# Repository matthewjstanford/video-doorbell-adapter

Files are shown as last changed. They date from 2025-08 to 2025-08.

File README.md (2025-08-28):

# Doorbell Circuit

This document describes the doorbell circuit project, why it is needed, and how I propose to solve the problem.

## Current Configuration

As of the start of this project the configuration is:

* Two Ubiquiti Doorbell buttons deployed, one at the front door, one at the side door
* The transformer is 3016MT 16V 30VA Doorbell Transformer
* Both doorbells are configured to use the doorbell adapter
* Chime is Broan mechanical chime
* Doorbell buttons are connected to the network via WiFi

### Theory of Operation

This is my understanding of how the system operates.

1. 16VAC is supplied by the transformer to the chimes
1. The doorbell button is connected to the chimes so that the current being supplied to the doorbell button passes through the chime coil.
1. Under normal conditions (doorbell button is not pushed) the doorbell button can draw a small amount of current (how much?) and not activate the chime.
1. When the button is pressed a relay is closed that shorts the wires in the doorbell button. This causes a large amount of current to flow through the circuit, which activates the chime coil.
1. The doorbell buttons contain a small battery that allows it to handle surges of power draw without activating the chime.

## Problem

There are two distinct issues that I believe can both be solved with a single circuit design.

1. Under periods of sustained high load (on very cold days in the winter, when the battery is presumably underperforming) the additional current draw will cause the chimes to hum. The hum is the striker vibrating within the coil.
1. I would like to replace the cheap Broan mechanical chimes with a much nicer 8 tone chime. These type of chimes are not compatible with the Ubiquiti style doorbell buttons.
    1. The chime is connected directly to the transformer.
    1. Activating the chime requires shorting a pin to one of the transformer leads. Since current isn't flowing continually through the doorbell buttons it can't work with a video doorbell. (See wiring diagram below)
    1. Since the trigger mechanism is quite different (current draw vs shorting a pin) there is no direct way to get the Ubiquiti buttons to work with the new chime.
    
**Simple Chime Wiring**

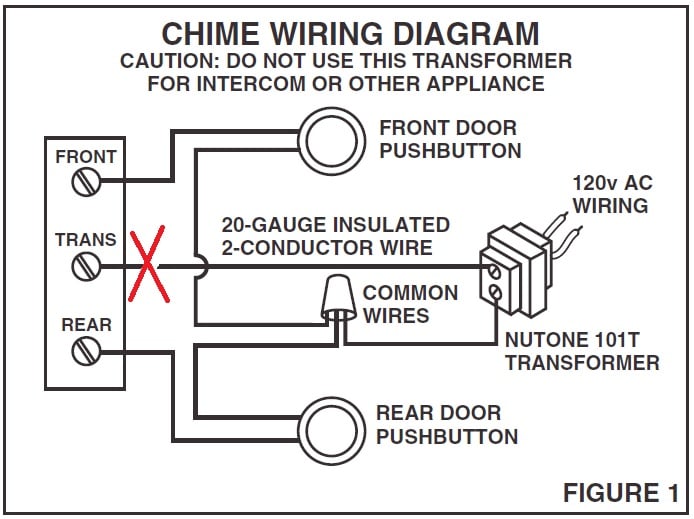
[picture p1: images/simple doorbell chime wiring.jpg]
Simple Chime Wiring


**New Chime Wiring**

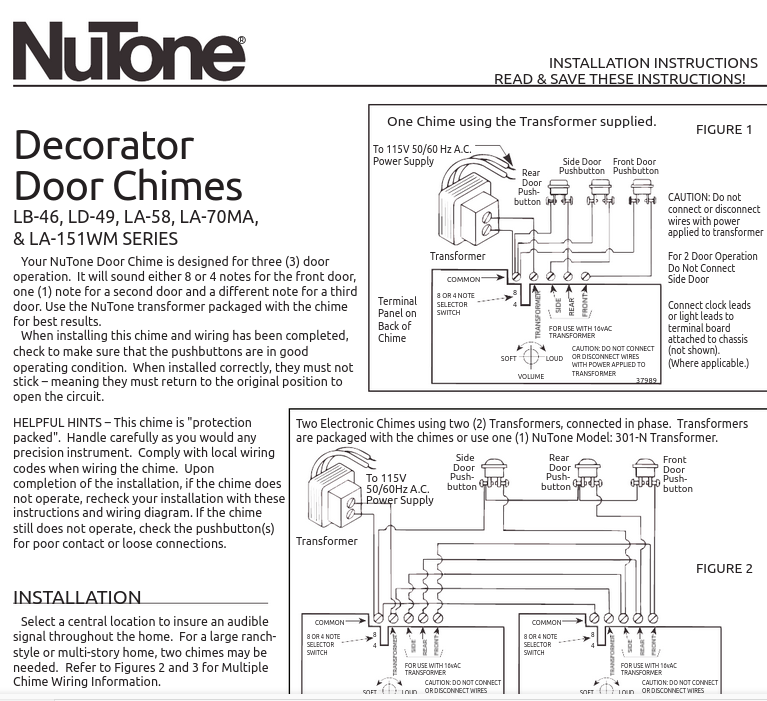
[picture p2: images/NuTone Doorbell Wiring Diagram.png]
NuTone Chime Wiring


**UniFi Protect Wiring**

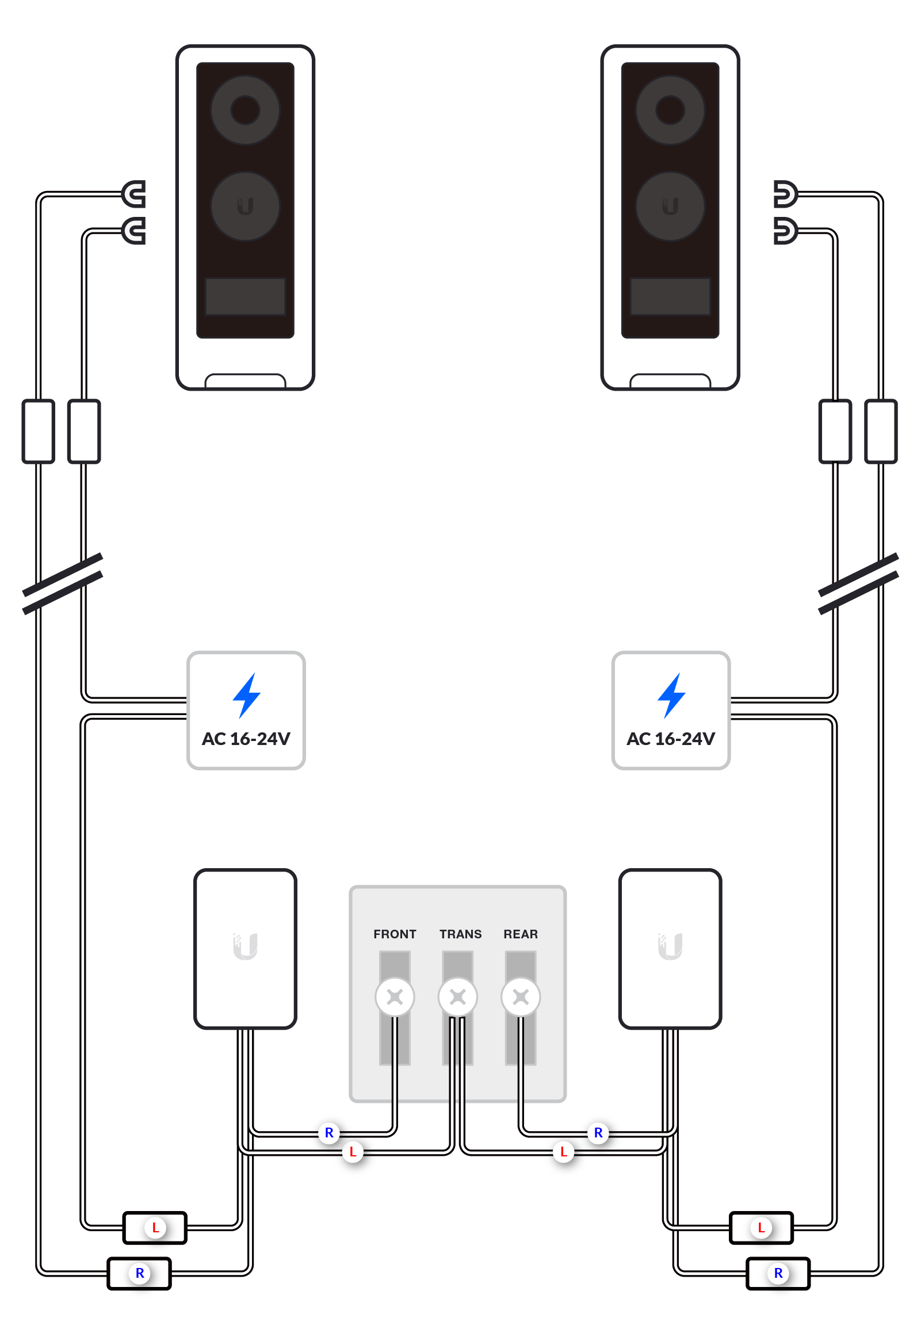
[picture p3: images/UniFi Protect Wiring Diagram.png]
UniFi Protect Wiring


## Idea

The general idea is to design a circuit that will sit in between the chime and the doorbell buttons. This circuit will constantly supply the buttons with current, and then will detect when current draw exceeds a threshold. Upon triggering the circuit will close a relay for a short period of time. The relay pins can be used to activate the Broan style current chime, or can be used to short the pin on the new style chime.

## Goals

Net power consumption on this circuit is a bit of a concern. Each additional doorbell button adds more load. The 30VA transformer should be quite sufficient for two doorbells and either chime configuration. We should keep the power consumption of the new circuit to a minimum.

I'd like to do this without using a microcontroller of any sort. We should be able to design this circuit with discrete components and build adjustability into things with potentiometers.

## Unknowns

The Ubiquiti doorbell buttons come with "doorbell adapters" that go in parallel with the doorbell button itself. What do those do? Are the capacitors?

How many doorbell buttons/chime configurations should the design support? It should support at least two, but should it support 3 or 4? In case more are added?

## Circuit Design

* A current transformer will be used to measure the current that is sent to the doorbell button.
* The CT output will be rectified into DC (peak detector) and fed into an OpAmp.
* The OpAmp will be configured as an inverting comparator with a potentiometer on the Vref to make the threshold tunable.
* The output of the OpAmp will be fed into a 555 timer in Monostable configuration.
* The 555 timer output can directly actuate a relay.
* Most of the circuit design is DC, so we will need to convert from 16VAC to 12VDC. Since power consumption is a primary goal we should use a buck/switching power supply. A switching regulator like the LM2575 should work.

## Discrete Components

And a brief description of why these specific components were selected.

* OpAmp - LM358
    * I had a bunch of these from a previous project.
* Switching Regulator - LM2575-12WT
    * A switching regulator was selected for power efficiency sake, and 12V was selected because it is near the input AC voltage and also because we will need to operate relays. Lower voltage relays are available, but we want to manage current by using higher voltage.
* Current Transformer - CT05-1000
    * This was selected for its small form factor and turn ratio. 1000:1. A 1A primary current will result in 1mA secondary.
* Burden Resistor - 6k (1A (est)/1000 = 1mA; 6V (half of 12V) / 1mA = 6k)
    * Assuming the doorbell will consume 1A when the button is pressed, we want around a 6V voltage spike as input to the OpAmp.

## Things I learned along the way

* The LM358 is a "single source" OpAmp, so it does not need a virtual ground
* A simple peak detector, like what we are considering here, should work great for this application.
* A 16 VAC source (our Doorbell transformer) will be close to 21 VDC once rectified. Using LM2575 to regulate it to 12 V should be totally fine.
* A linear voltage regulator is sometimes required after a switching regulator like the LM2575. This is because the switching regulator can introduce noise. In our case, however, this likely won't be an issue. No linear regulator should be required.

## Sub Assemblies

### Power Supply

The power supply needs to convert 16VAC to 12VDC and it needs to be as efficient as possible. The switching regulator, LM2575-12WT, is not adjustable. It will output 12V.

The AC input is rectified using 4 1N4002 diodes and a 470uF smoothing capacitor. The remainder of the circuit is based on the LM2575-12WT data sheet. A 330uF capacitor, 330uH inductor, and a 1N5817 Schottky diode are being used. The diode does not need to be a Schottky diode, but we are using the 1N5817 in other parts of the circuit, so we're just using it here now.

### Current Sensor

I am using a 1000:1 current transformer with a 6k burden resistor. This means that a 1A current on the primary should result in 1mA current on the secondary. 1mA across a 6k resistor should result in 6V. However, the 6V signal will only last a few milliseconds as this is a sine wave.

#### Peak Detector

The peak detector is meant to capture that peak voltage and store it for a period of time. This is to provide the downstream 555 timer a strong signal.

V(t)=V<sub>0</sub>e^−t/(RC)

* R=10 kΩ ( 1 x 10^4 )
* C=10 μF ( 1 x 10^-5 )
* Therefore RC = 1 x 10^-1 , or 0.1s or 100ms

In other words the voltage should decay 37% from the peak in around 100ms.

#### Amplifier

The operational amplifier is here to both invert the peak signal (take the voltage to zero) and to decouple the input signal from what we feed to the 555 timer.

### Timer

The timer portion of this circuit is necessary so that we can simulate a normal "press" of a doorbell button. This corresponds to the amount of time the relay stays closed.

The target should be around how long a doorbell button is normally held in the pressed position. But how long is that? Based on my own observation I suspect this is somewhere between 1/2 and 1 second.

As such I want the timer to stay activated somewhere in that range, but it should also be adjustable.

From the datasheet:

> For mono-stable operation, any of these timers can be connected as shown in Figure 9. If the output is low, application of a negative-going pulse to the trigger (TRIG) sets the flip-flop (Q goes low), drives the output high, and turns off Q1. Capacitor C then is charged through RA until the voltage across the capacitor reaches the threshold voltage of the threshold (THRES) input. If TRIG has returned to a high level, the output of the threshold comparator resets the flip-flop (Q goes high), drives the output low, and discharges C through Q1.

> Monostable operation is initiated when TRIG voltage falls below the trigger threshold. Once initiated, the sequence ends only if TRIG is high for at least 10 μs before the end of the timing interval. When the trigger is grounded, the comparator storage time can be as long as 10 μs, which limits the minimum monostable pulse width to 10 μs. Because of the threshold level and saturation voltage of Q1, the output pulse duration is approximately tw = 1.1RAC. Figure 11 is a plot of the time constant for various values of RA and C. The threshold levels and charge rates both are directly proportional to the supply voltage, VCC. The timing interval is, therefore, independent of the supply voltage, so long as the supply voltage is constant during the time interval.
Applying a negative-going trigger pulse simultaneously to RESET and TRIG during the timing interval discharges C and reinitiates the cycle, commencing on the positive edge of the reset pulse. The output is held low as long as the reset pulse is low. To prevent false triggering, when RESET is not used, it should be connected to VCC.

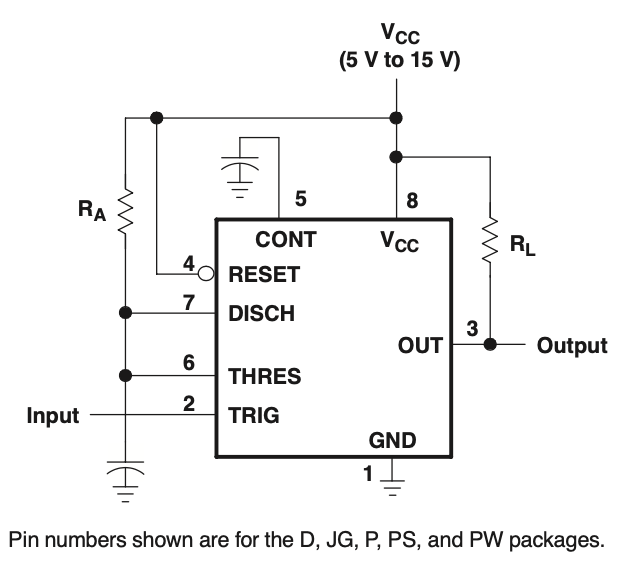
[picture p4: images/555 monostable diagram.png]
Monostable sample circuit 555 Monostable Schematic


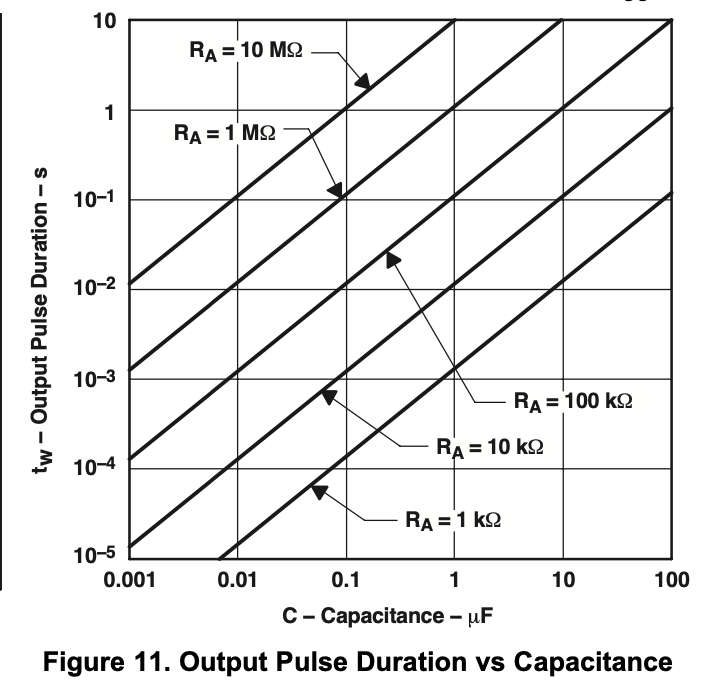
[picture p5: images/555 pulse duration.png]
Pulse duration


Using these charts we can see that with a 10uF capacitor and a 100k resistor (R<sub>A</sub> in diagram) we should be in the neighborhood of 1 second pulse duration. Varying the resistance with a 100k potentiometer will allow us to make adjustments to reduce the pulse duration.

## Breadboarding and testing

Several things got me along the way. Thankfully I was able to work through the issues.

This testing was done using a spare 120VAC -> 16VAC doorbell transformer that I purchased specifically for these tests.

1. Breadboard the 12V power supply
    1. Originally I had connected the diode backwards, which obviously won't work. Once that was corrected the power supply 
1. Breadboard the current sensor, and power it by the power supply
    1. I went through the current sensor first, then the peak detector, then the operational amplifier. I was able to confirm that a dead short on the 16VAC primary side of the CT resulted in around 5.6V across the burden resistor on the secondary. This is a little lower than I had anticipated, but it is fully in the range that should be workable.
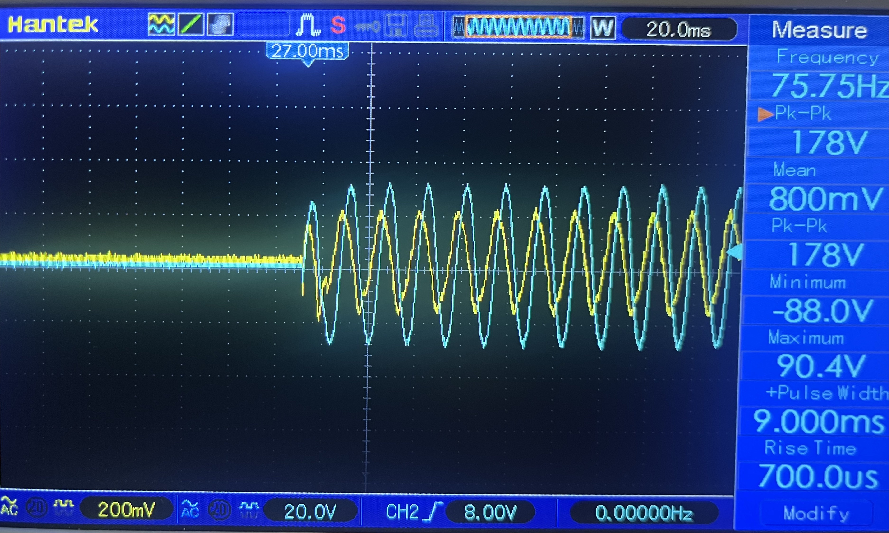
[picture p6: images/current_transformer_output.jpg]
Current Transformer

    1. I had made a mistake when creating the schematic of the peak detector. I had originally had the 10uF capacitor in-line between the diode and the OpAmp. Obviously this won't work. Once I realized my mistake I switched that capacitor to go between the output and ground, and things look good.
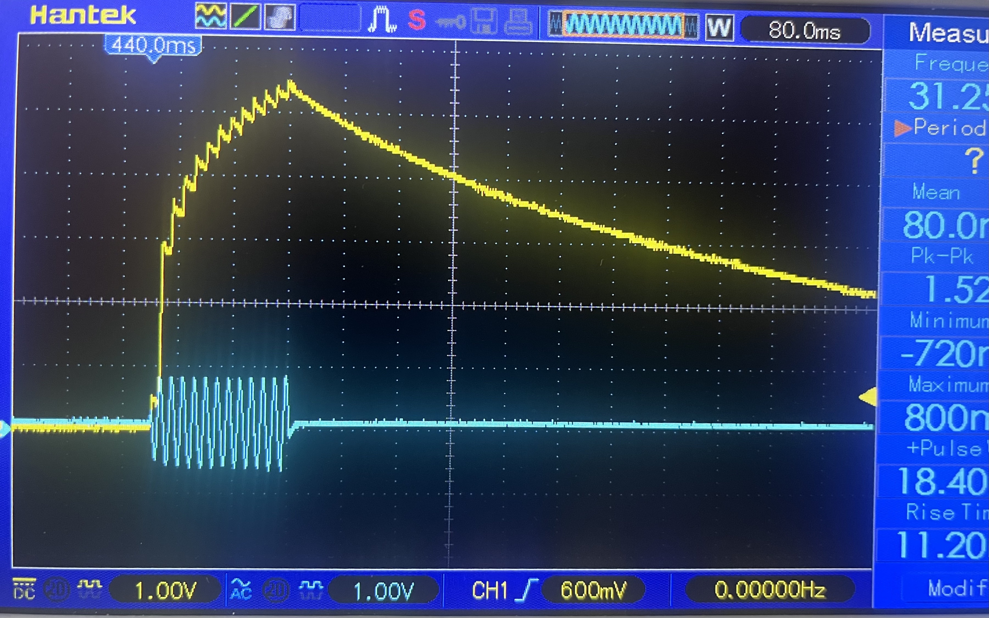
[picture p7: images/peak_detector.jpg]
Peak Detector

    1. I could not get the OpAmp to work correctly on the bench. I had the LM358 wired up according to the data sheet & schematic, but it didn't seem to be doing anything. Additionally I could see that the non-inverting input pin was sitting around 11V, where it should be 4V (voltage divider from potentiometer). Turns out I did have the chip wired correctly, but I had a broken wire, so the device wasn't grounded. Once that wire was replaced everything behaved as expected.
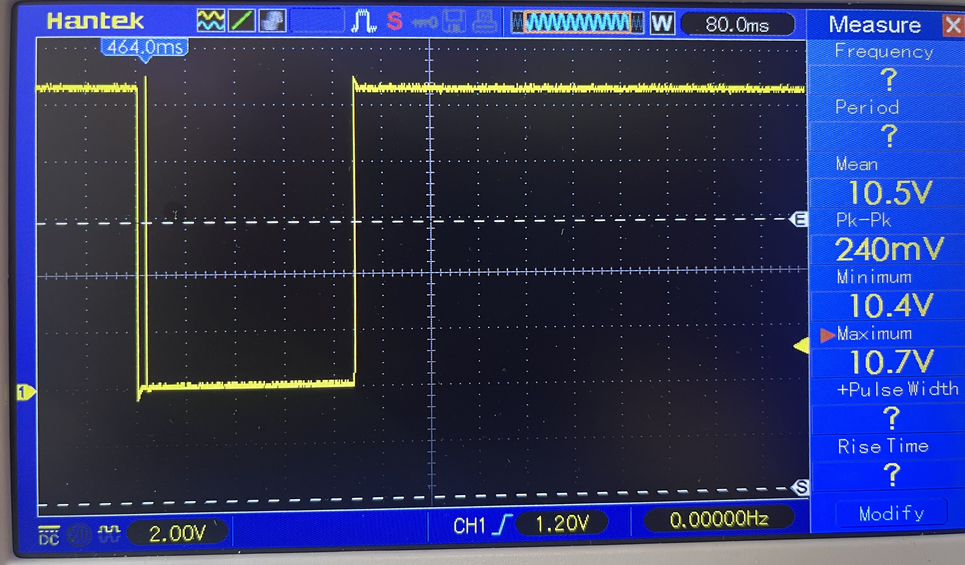
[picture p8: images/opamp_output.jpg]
OpAmp

1. Breadboard the timer & relay
    1. The timer circuit was verified on the bench and worked right out of the box. No issues were encountered here. I did confirm that the potentiometer would adjust the "press time". By default (middle of the range) the press time was around 0.7s.
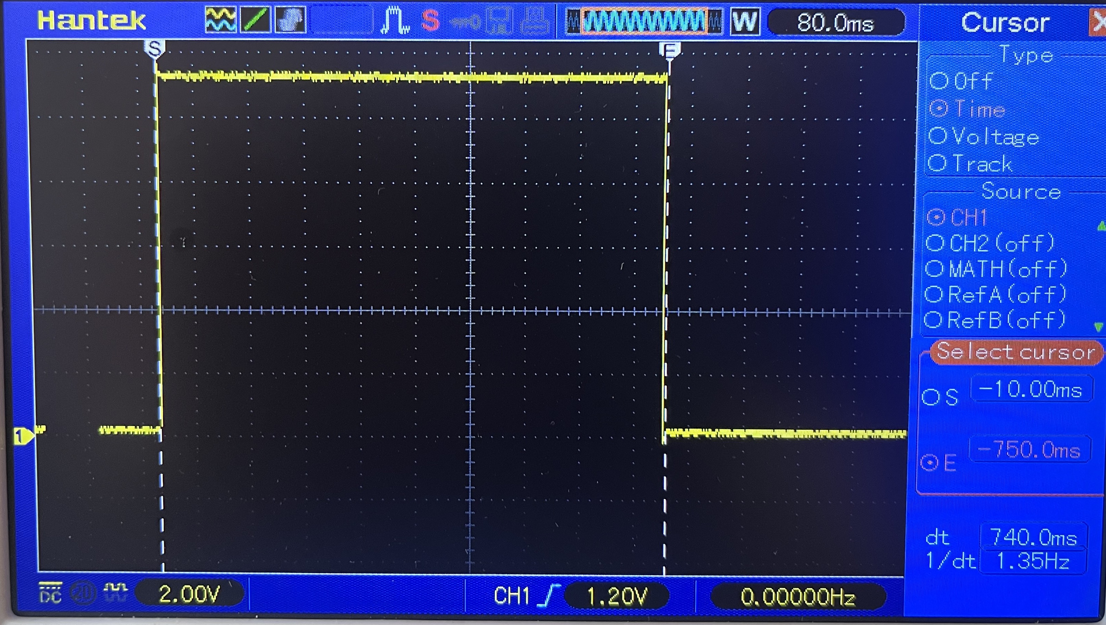
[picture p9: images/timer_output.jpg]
Timer Output

1. Switch simple doorbell button to a video doorbell
    1. I don't have a spare video doorbell, so this step was skipped for now.
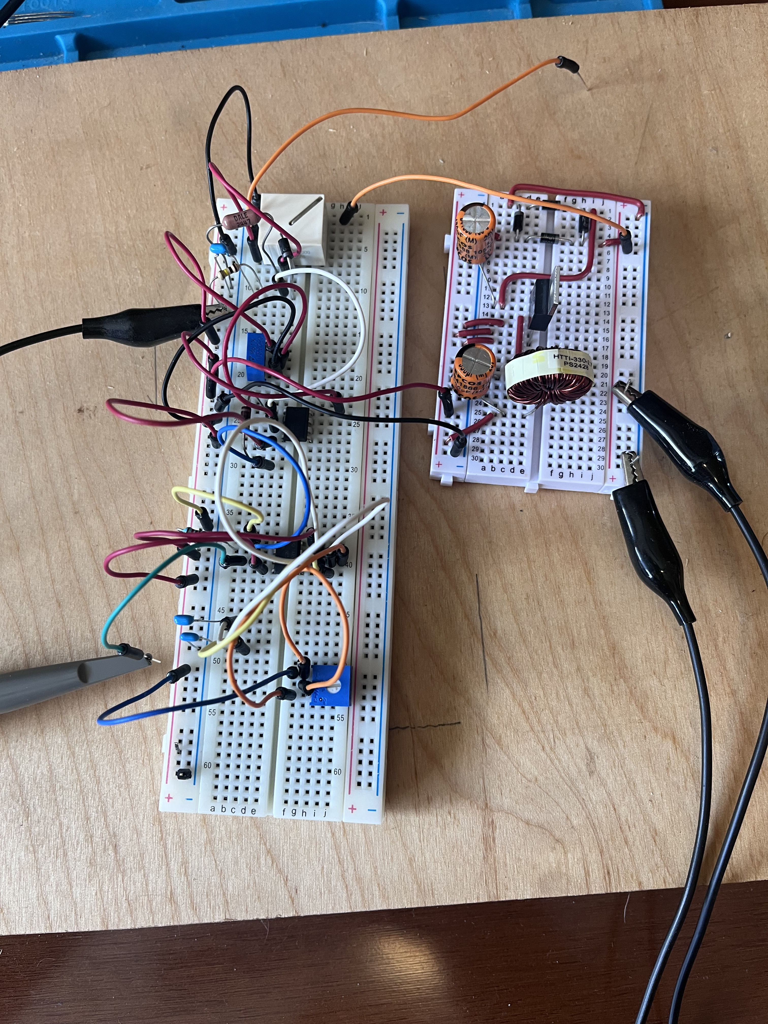
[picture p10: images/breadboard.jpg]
breadboard breadboard construction

1. Design PCB in KiCad
    1. This was my first ever PCB layout & creation. I had good design intentions when starting the layout, but it quickly devolved into chaos. I've come to realize that intuition is a key component to good design. That probably applies to all disciplines.
    1. I believe what I ended up with is a functional PCB, but it isn't pretty. Because this is my first ever layout, I'm running with it. I fairly certain if I were to start with a clean sheet and do it all again I would end up with a much better product. If it turns out there are any issues with the PCB then I'll just start over.
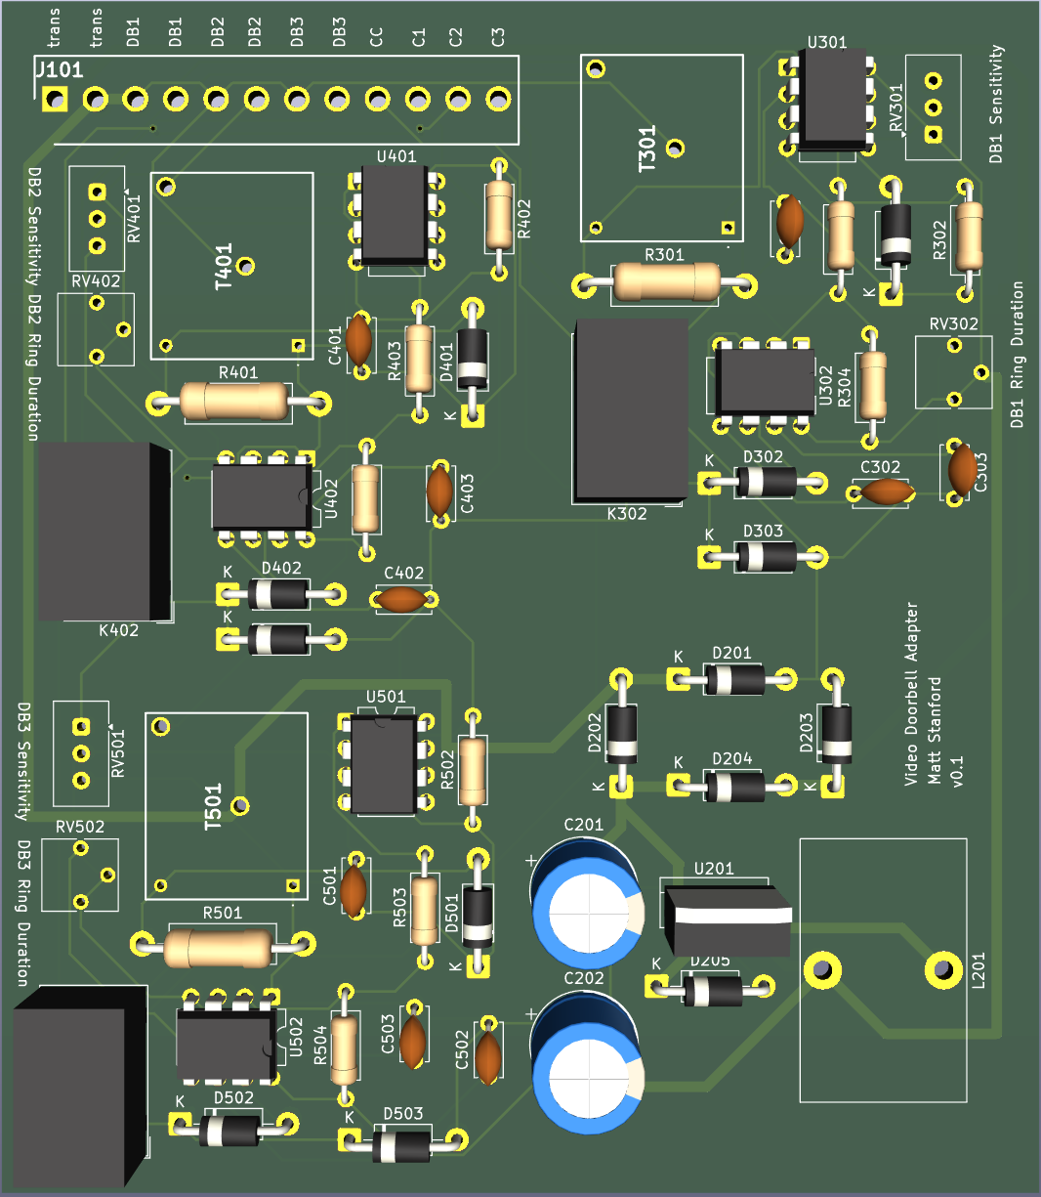
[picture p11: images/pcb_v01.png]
pcb PCB Image


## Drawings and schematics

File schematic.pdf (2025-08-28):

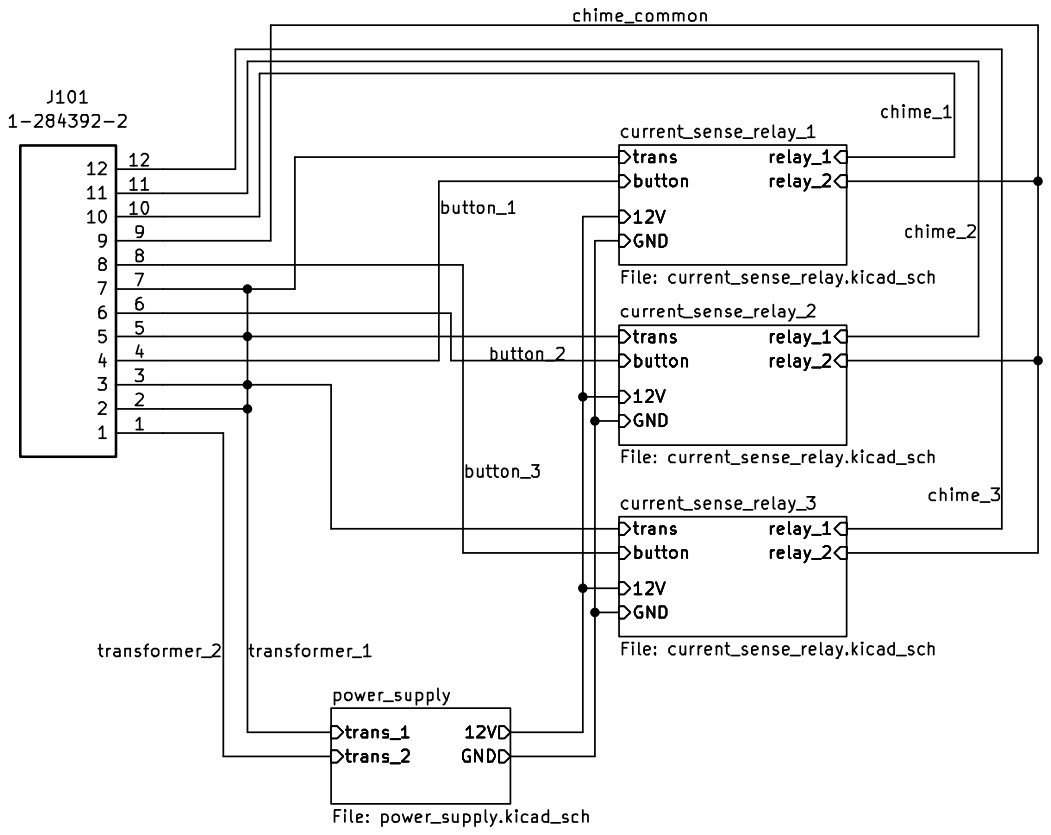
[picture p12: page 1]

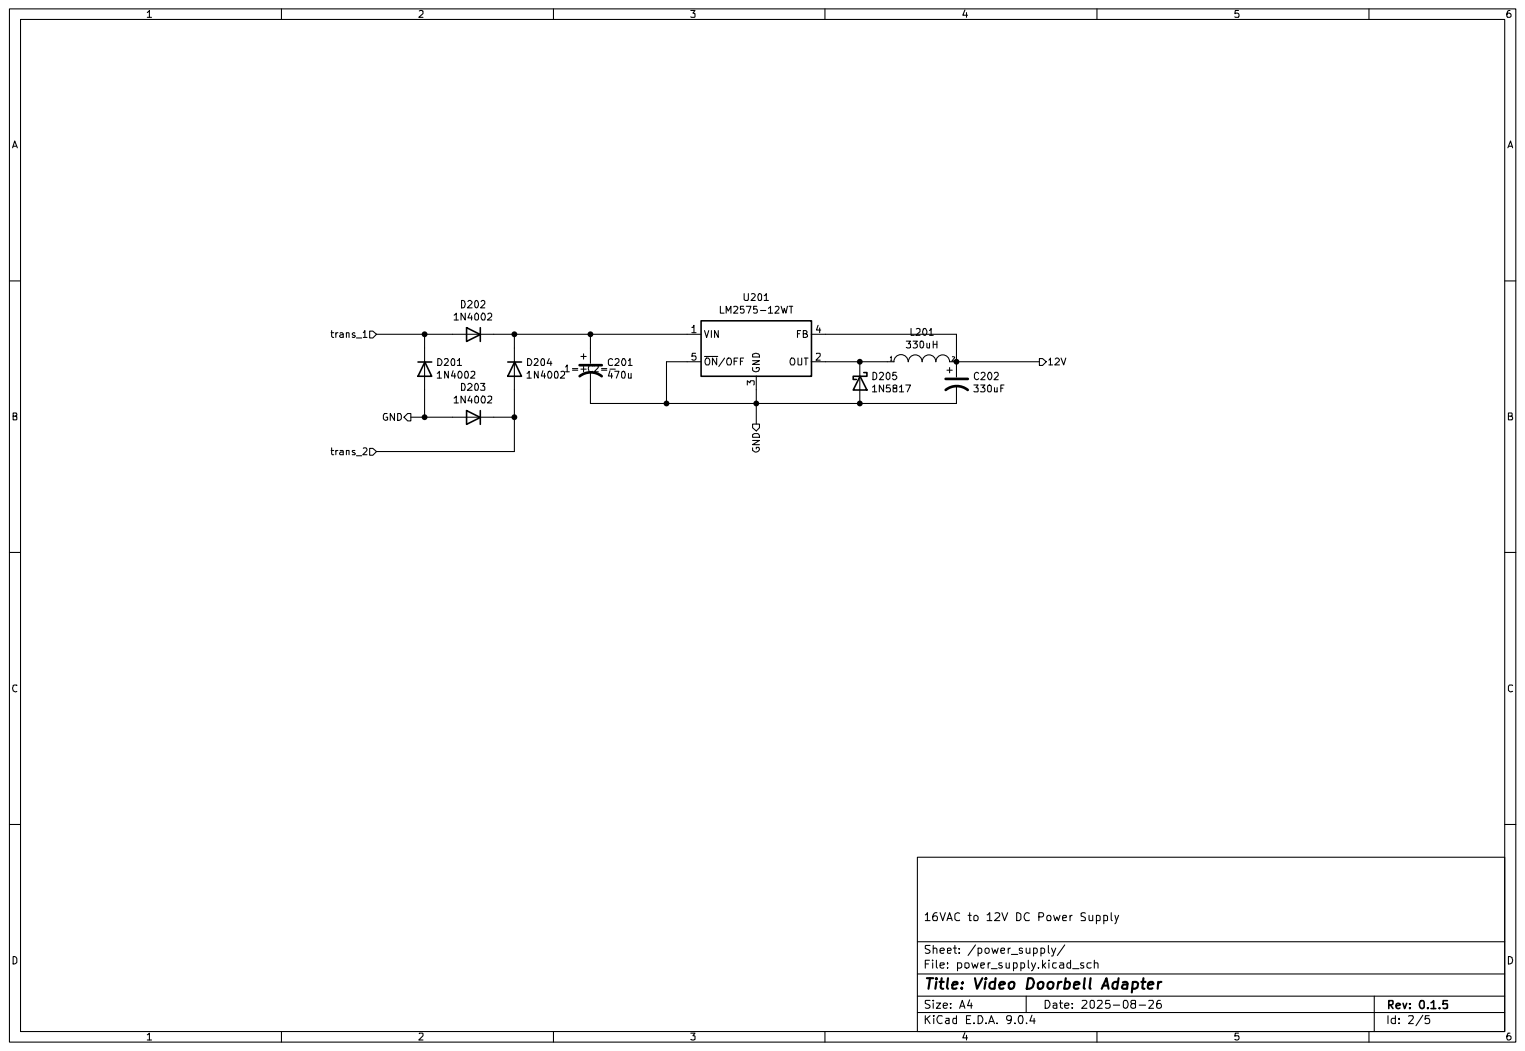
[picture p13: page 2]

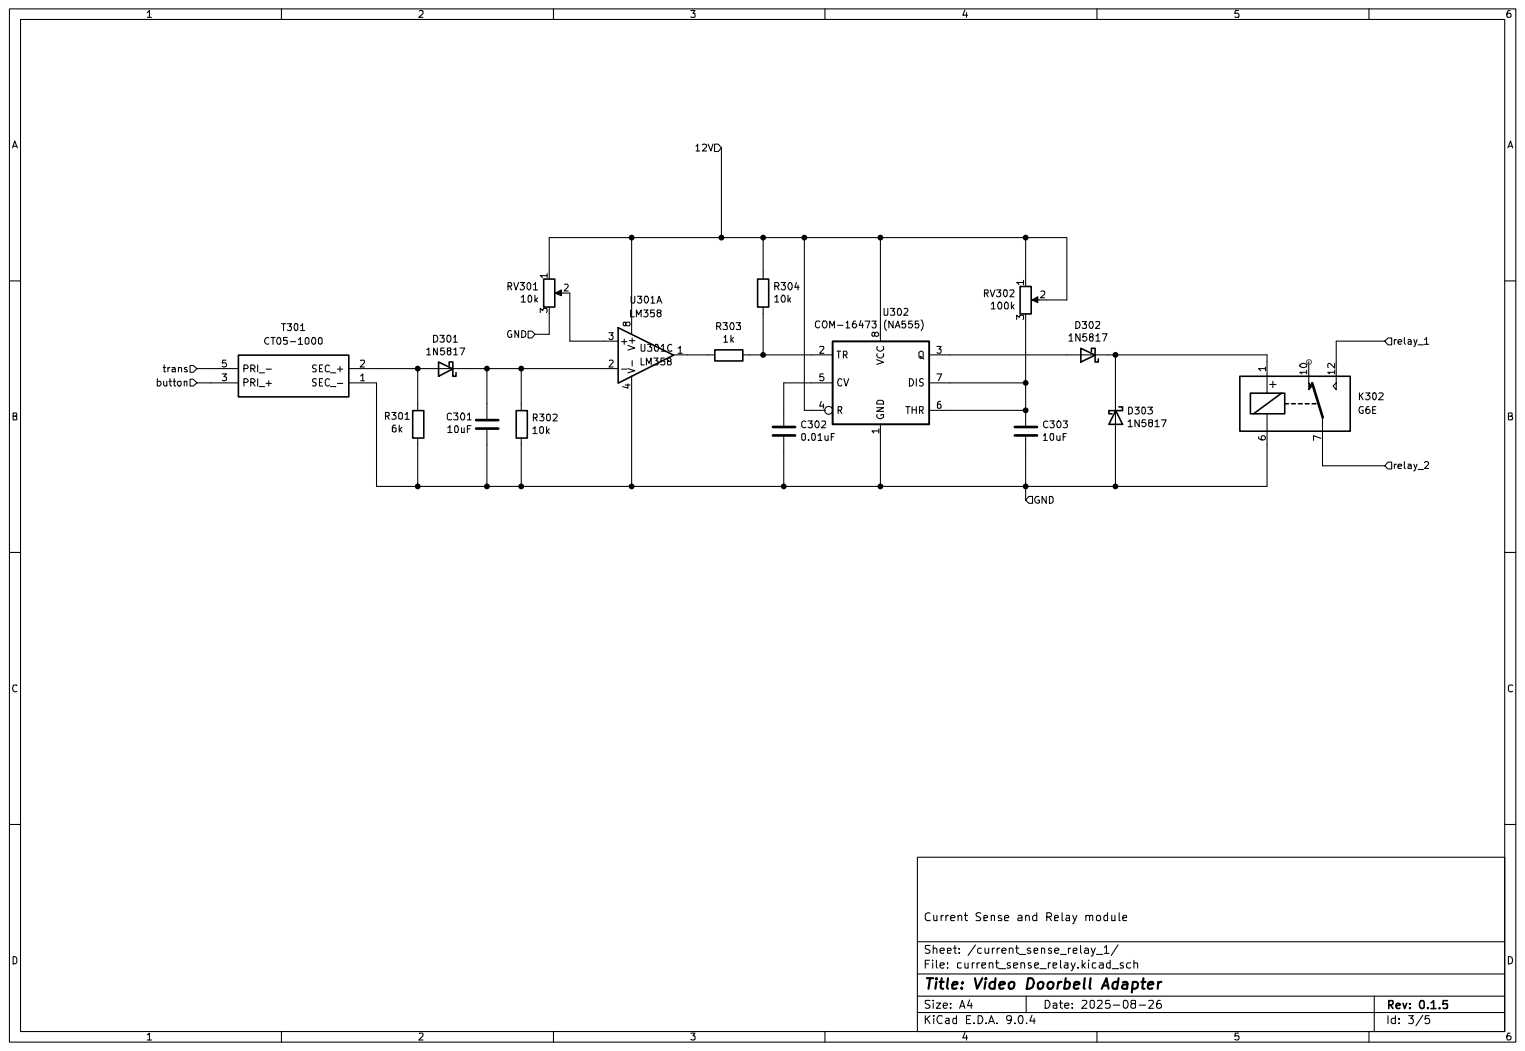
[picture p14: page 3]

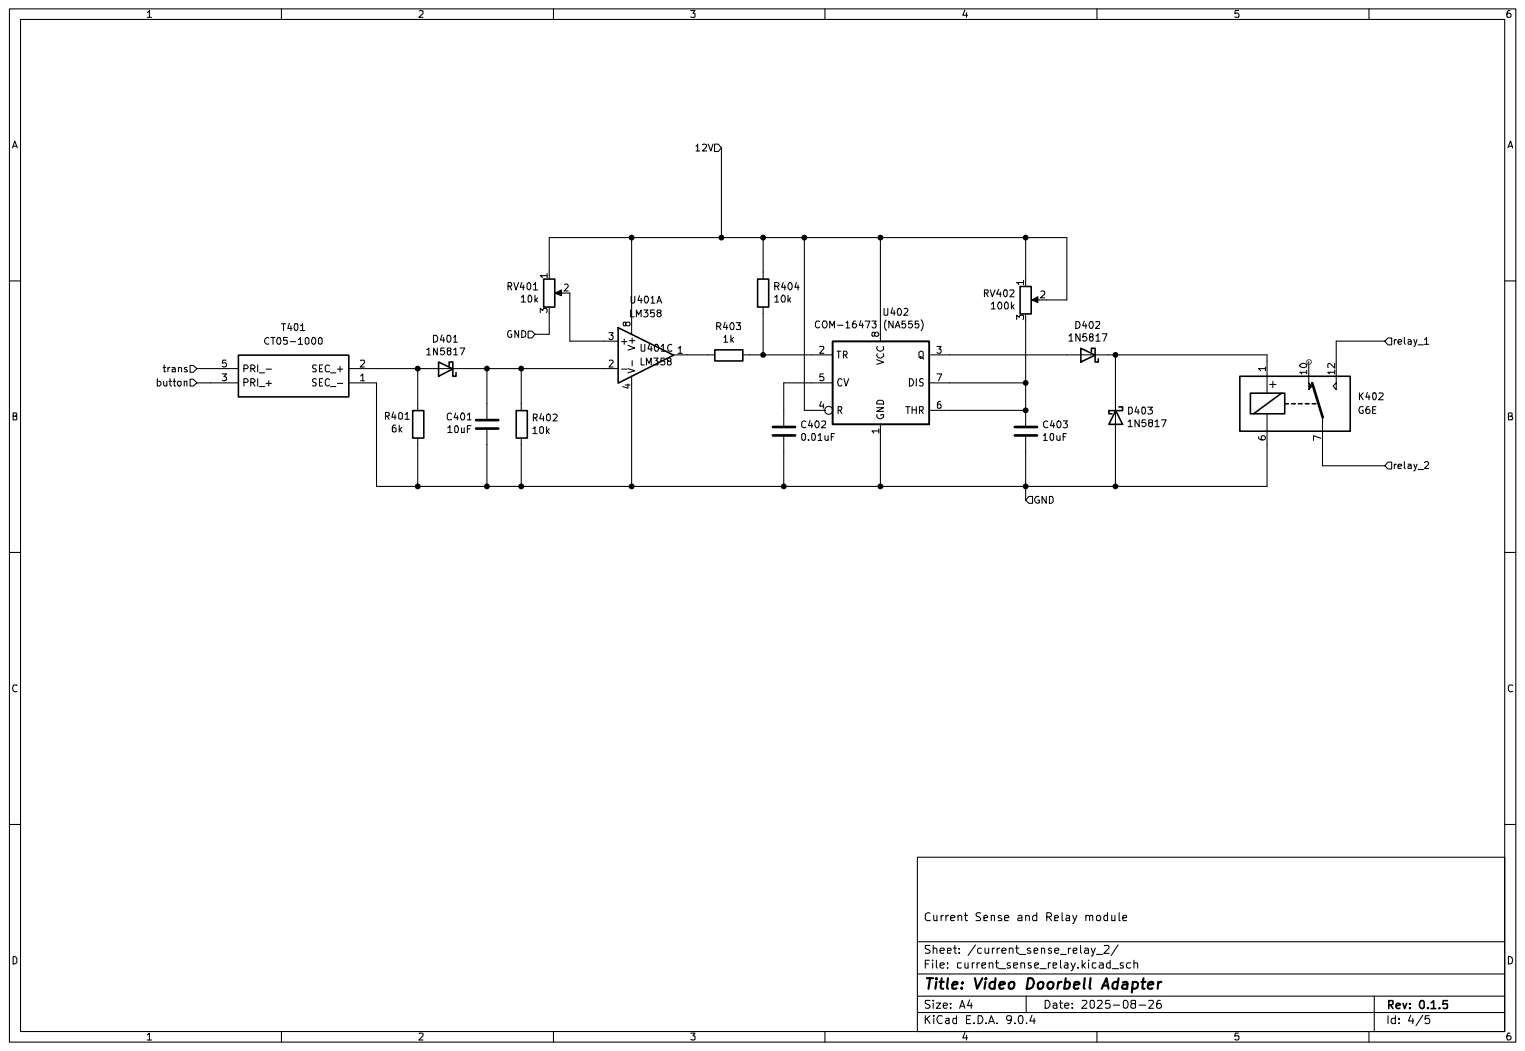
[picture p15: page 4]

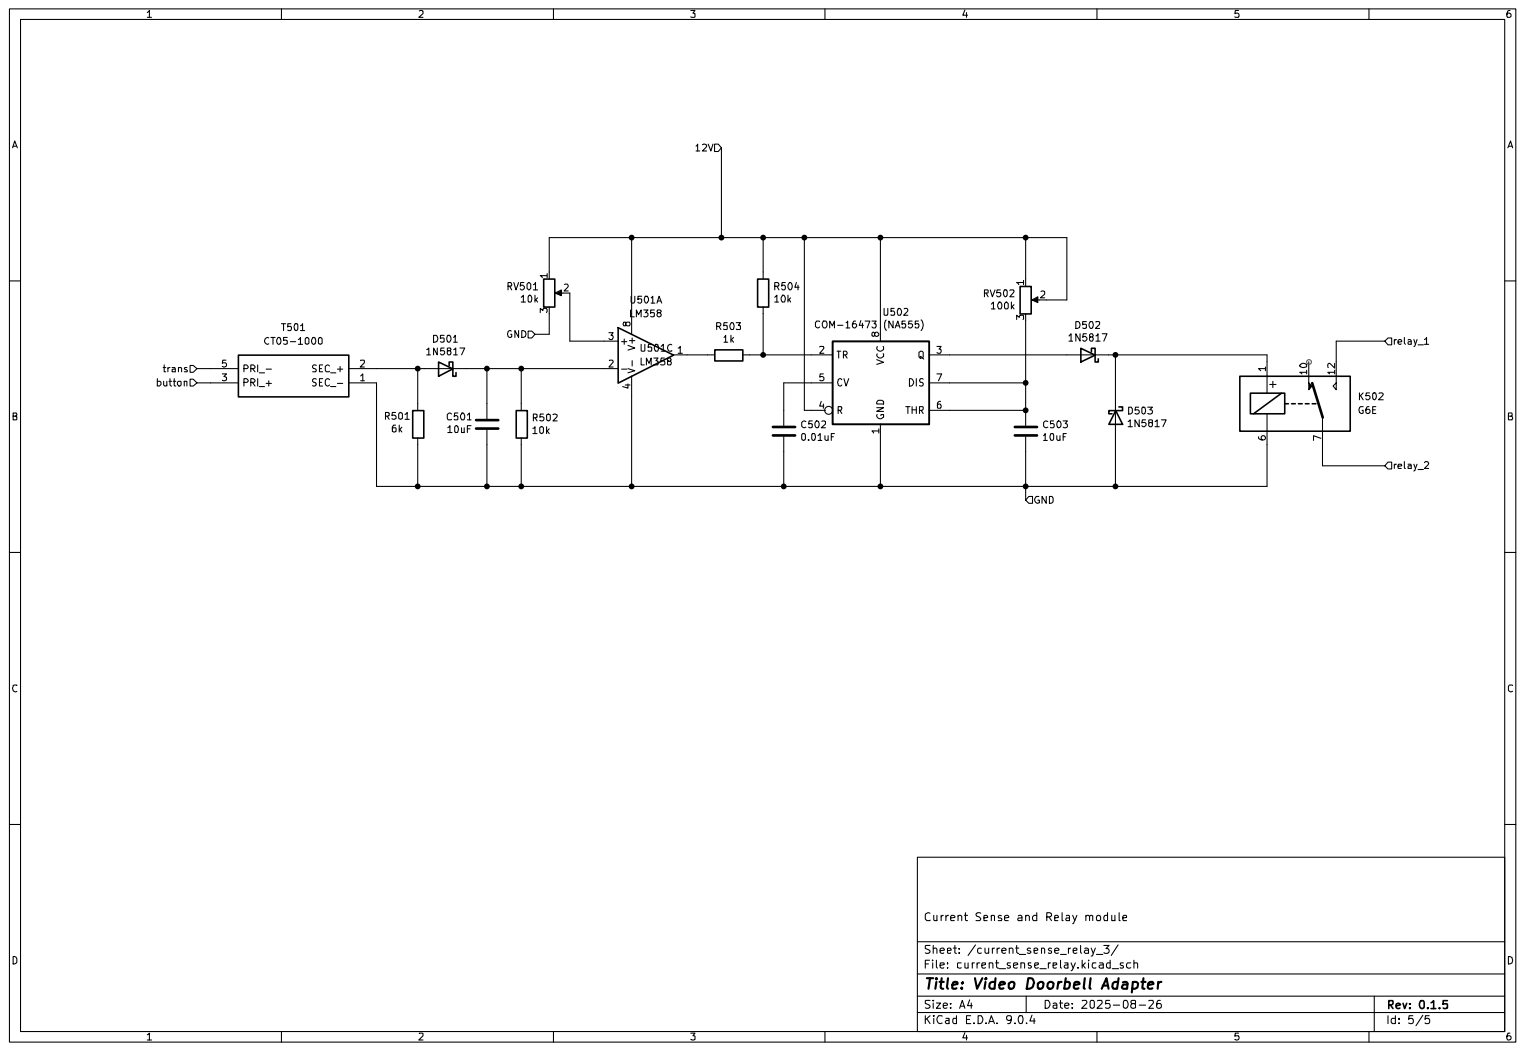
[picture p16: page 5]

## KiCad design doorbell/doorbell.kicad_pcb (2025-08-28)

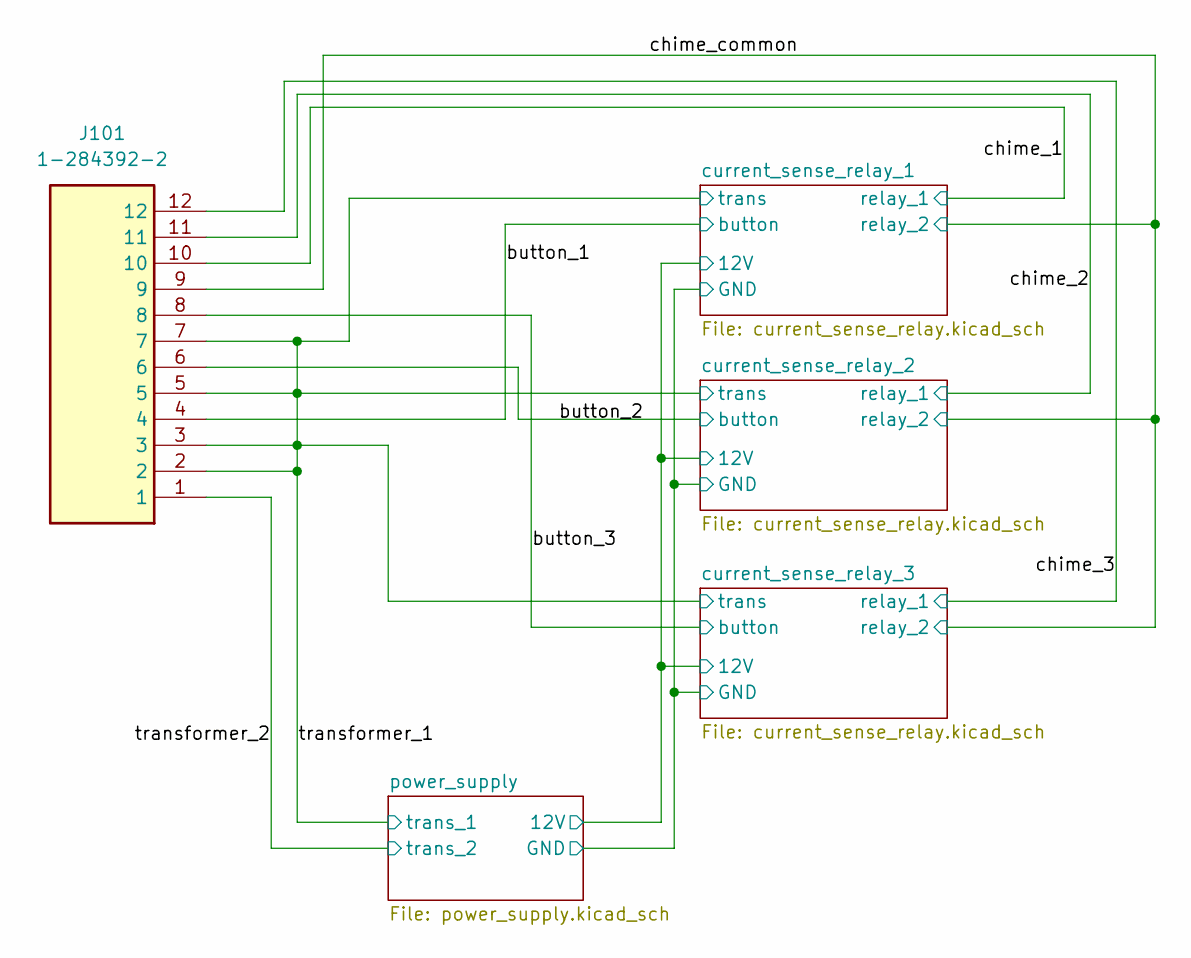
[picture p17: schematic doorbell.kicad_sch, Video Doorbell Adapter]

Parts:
J101: 1-284392-2; SHDR12W100P0X381_1X12_4572X820X1280P; Mouser Part Number 571-1-284392-2

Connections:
/button_1: J101.4; also elsewhere on the board
/button_3: J101.8; also elsewhere on the board
/chime_1: J101.10; also elsewhere on the board
/chime_2: J101.11; also elsewhere on the board
/chime_3: J101.12; also elsewhere on the board
/chime_common: J101.9; also elsewhere on the board
/current_sense_relay_2/button: J101.6; also elsewhere on the board
/transformer_1: J101.2, J101.3, J101.5, J101.7; also elsewhere on the board
/transformer_2: J101.1; also elsewhere on the board

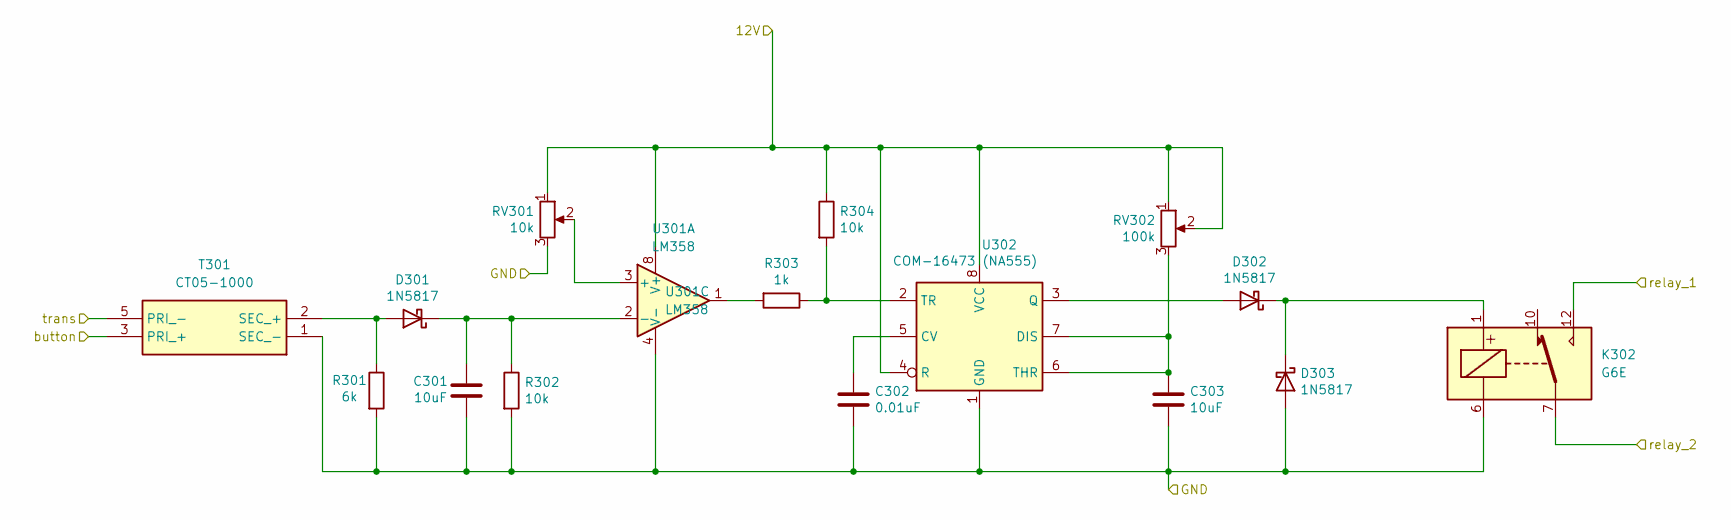
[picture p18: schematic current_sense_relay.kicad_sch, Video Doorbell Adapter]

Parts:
C301, C303: 10uF; C_Disc_D5.0mm_W2.5mm_P5.00mm
C302: 0.01uF; C_Disc_D5.0mm_W2.5mm_P5.00mm
D301, D302, D303: 1N5817; D_DO-41_SOD81_P10.16mm_Horizontal
K302: G6E; Relay_SPDT_Omron_G6E
R301: 6k; R_Axial_DIN0411_L9.9mm_D3.6mm_P15.24mm_Horizontal
R302, R304: 10k; R_Axial_DIN0207_L6.3mm_D2.5mm_P10.16mm_Horizontal
R303: 1k; R_Axial_DIN0207_L6.3mm_D2.5mm_P10.16mm_Horizontal
RV301: 10k; Potentiometer_Vishay_T93YA_Vertical
RV302: 100k; Potentiometer_Vishay_T73YP_Vertical
T301: CT05-1000; CT051000; Mouser Part Number 911-CT05-1000
U301: LM358; DIP-8_W7.62mm
U302: COM-16473 (NA555); DIP-8_W7.62mm

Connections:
/button_1: T301.3 (PRI_+); also elsewhere on the board
/chime_1: K302.12; also elsewhere on the board
/chime_common: K302.7; also elsewhere on the board
/current_sense_relay_1/12V: R304.1, RV301.1, RV302.1, RV302.2, U301.8 (V+), U302.4 (R), U302.8 (VCC); also elsewhere on the board
/current_sense_relay_1/GND: C301.2, C302.2, C303.2, D303.2 (A), K302.6, R301.2, R302.2, RV301.3, T301.1 (SEC_-), U301.4 (V-), U302.1 (GND); also elsewhere on the board
/transformer_1: T301.5 (PRI_-); also elsewhere on the board
unnamed: D301.2 (A), R301.1, T301.2 (SEC_+)
unnamed: C301.1, D301.1 (K), R302.1, U301.2 (-)
unnamed: D302.2 (A), U302.3 (Q)
unnamed: D302.1 (K), D303.1 (K), K302.1
unnamed: R303.2, U301.1
unnamed: RV301.2, U301.3 (+)
unnamed: C302.1, U302.5 (CV)
unnamed: C303.1, RV302.3, U302.6 (THR), U302.7 (DIS)
unnamed: R303.1, R304.2, U302.2 (TR)

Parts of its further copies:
C401, C403, C501, C503: 10uF; C_Disc_D5.0mm_W2.5mm_P5.00mm
C402, C502: 0.01uF; C_Disc_D5.0mm_W2.5mm_P5.00mm
D401, D402, D403, D501, D502, D503: 1N5817; D_DO-41_SOD81_P10.16mm_Horizontal
K402, K502: G6E; Relay_SPDT_Omron_G6E
R401, R501: 6k; R_Axial_DIN0411_L9.9mm_D3.6mm_P15.24mm_Horizontal
R402, R404, R502, R504: 10k; R_Axial_DIN0207_L6.3mm_D2.5mm_P10.16mm_Horizontal
R403, R503: 1k; R_Axial_DIN0207_L6.3mm_D2.5mm_P10.16mm_Horizontal
RV401, RV501: 10k; Potentiometer_Vishay_T93YA_Vertical
RV402, RV502: 100k; Potentiometer_Vishay_T73YP_Vertical
T401, T501: CT05-1000; CT051000; Mouser Part Number 911-CT05-1000
U401, U501: LM358; DIP-8_W7.62mm
U402, U502: COM-16473 (NA555); DIP-8_W7.62mm

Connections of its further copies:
/button_3: T501.3 (PRI_+); also elsewhere on the board
/chime_2: K402.12; also elsewhere on the board
/chime_3: K502.12; also elsewhere on the board
/chime_common: K402.7, K502.7; also elsewhere on the board
/current_sense_relay_1/12V: R404.1, R504.1, RV401.1, RV402.1, RV402.2, RV501.1, RV502.1, RV502.2, U401.8 (V+), U402.4 (R), U402.8 (VCC), U501.8 (V+), U502.4 (R), U502.8 (VCC); also elsewhere on the board
/current_sense_relay_1/GND: C401.2, C402.2, C403.2, C501.2, C502.2, C503.2, D403.2 (A), D503.2 (A), K402.6, K502.6, R401.2, R402.2, R501.2, R502.2, RV401.3, RV501.3, T401.1 (SEC_-), T501.1 (SEC_-), U401.4 (V-), U402.1 (GND), U501.4 (V-), U502.1 (GND); also elsewhere on the board
/current_sense_relay_2/button: T401.3 (PRI_+); also elsewhere on the board
/transformer_1: T401.5 (PRI_-), T501.5 (PRI_-); also elsewhere on the board
unnamed: D401.2 (A), R401.1, T401.2 (SEC_+)
unnamed: C401.1, D401.1 (K), R402.1, U401.2 (-)
unnamed: D402.2 (A), U402.3 (Q)
unnamed: D402.1 (K), D403.1 (K), K402.1
unnamed: D501.2 (A), R501.1, T501.2 (SEC_+)
unnamed: C501.1, D501.1 (K), R502.1, U501.2 (-)
unnamed: D502.2 (A), U502.3 (Q)
unnamed: D502.1 (K), D503.1 (K), K502.1
unnamed: R403.2, U401.1
unnamed: R503.2, U501.1
unnamed: RV401.2, U401.3 (+)
unnamed: C402.1, U402.5 (CV)
unnamed: C403.1, RV402.3, U402.6 (THR), U402.7 (DIS)
unnamed: R403.1, R404.2, U402.2 (TR)
unnamed: RV501.2, U501.3 (+)
unnamed: C502.1, U502.5 (CV)
unnamed: C503.1, RV502.3, U502.6 (THR), U502.7 (DIS)
unnamed: R503.1, R504.2, U502.2 (TR)

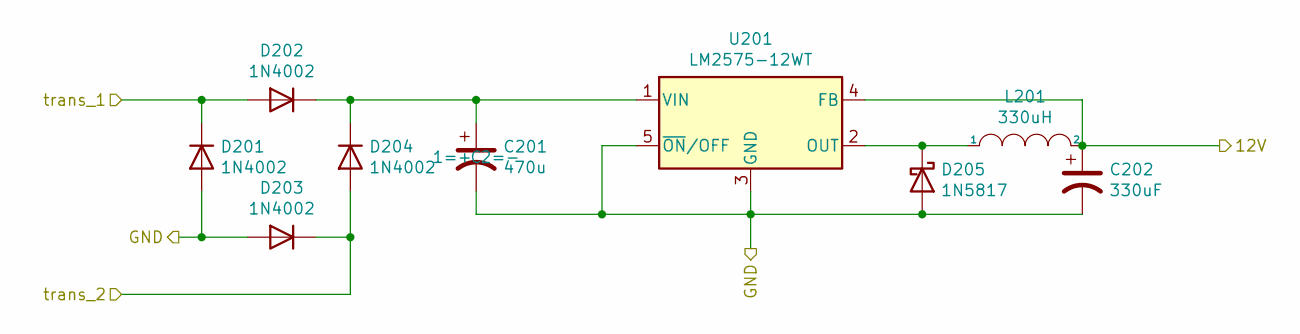
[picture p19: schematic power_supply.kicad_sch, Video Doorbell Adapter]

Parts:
C201: 470u; CP_Radial_D10.0mm_P5.00mm
C202: 330uF; CP_Radial_D10.0mm_P5.00mm
D201, D202, D203, D204: 1N4002; D_DO-41_SOD81_P10.16mm_Horizontal
D205: 1N5817; D_DO-41_SOD81_P10.16mm_Horizontal
L201: 330uH; L_Toroid_Vertical_L24.6mm_W15.5mm_P11.44mm_Pulse_KM-4
U201: LM2575-12WT; TO-262-5_Vertical

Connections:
/current_sense_relay_1/12V: C202.1, L201.2, U201.4 (FB); also elsewhere on the board
/current_sense_relay_1/GND: C201.2, C202.2, D201.2 (A), D203.2 (A), D205.2 (A), U201.3 (GND), U201.5 (~ON/OFF); also elsewhere on the board
/transformer_1: D201.1 (K), D202.2 (A); also elsewhere on the board
/transformer_2: D203.1 (K), D204.2 (A); also elsewhere on the board
unnamed: C201.1, D202.1 (K), D204.1 (K), U201.1 (VIN)
unnamed: D205.1 (K), L201.1, U201.2 (OUT)

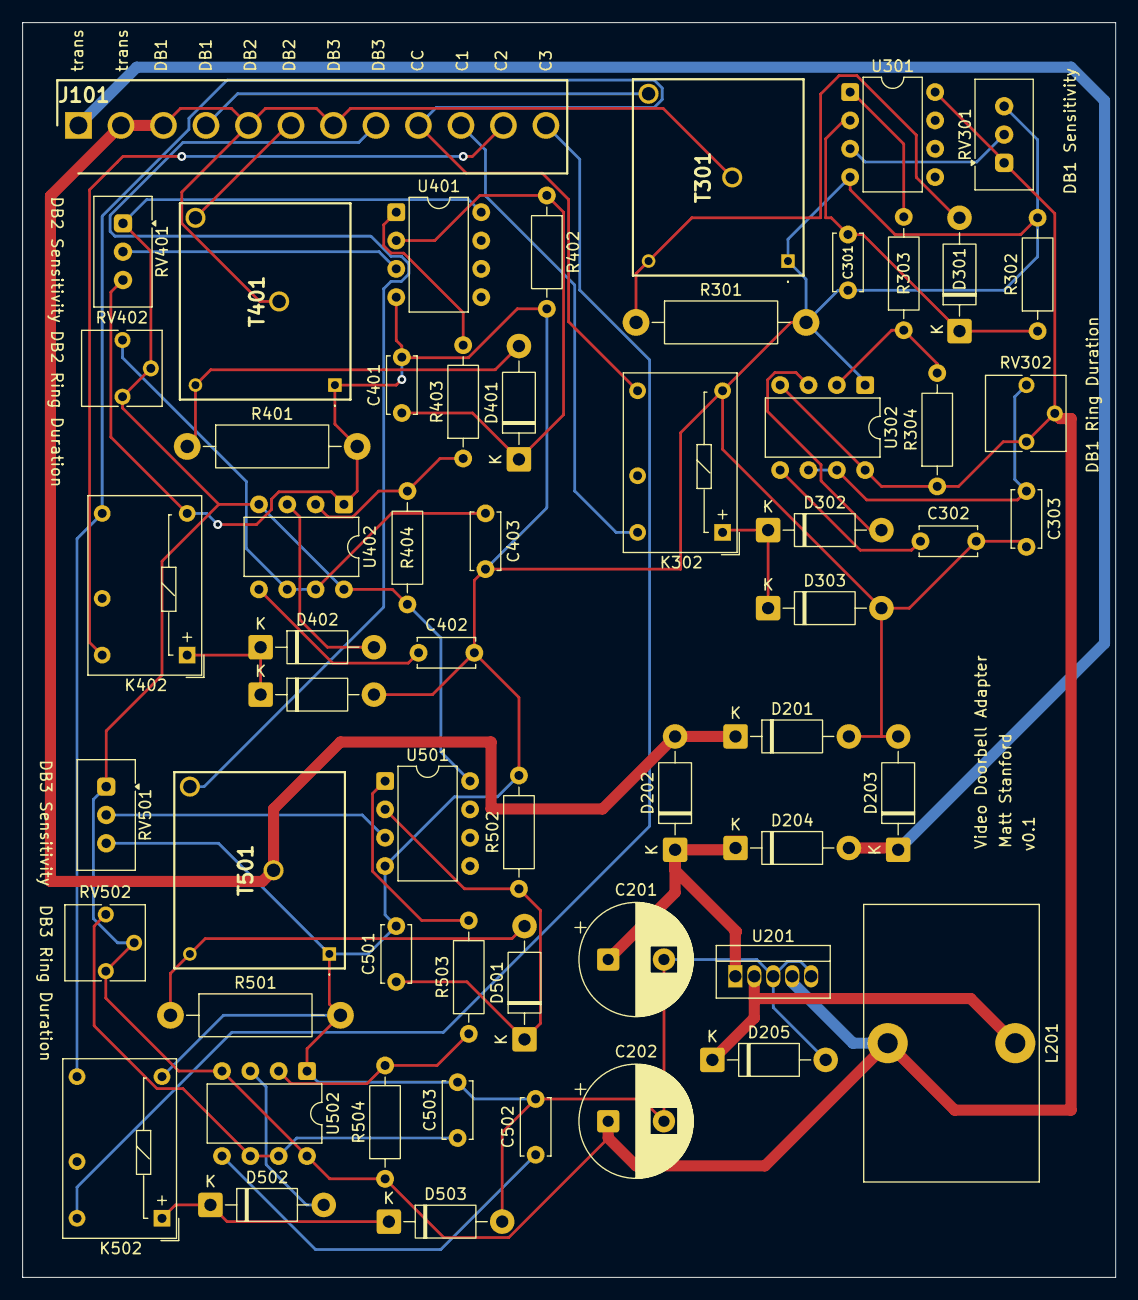
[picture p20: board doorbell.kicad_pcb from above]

Board: 2 copper layers, 98.0 x 112.5 mm, 58 parts (0 on the bottom side), 40 nets.

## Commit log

2025-08-05 Initial checkin. Adding README and schematic
    [doorbell.kicad_pcb, doorbell.sch]
2025-08-05 Adding PDF of schematic
2025-08-11 Adding more images
    [doorbell.sch]
2025-08-22 v0.1.3 - adjusted some diodes. Updated readme
    [doorbell.kicad_pcb, doorbell.sch]
2025-08-24 Updating readme and peak detector
    [doorbell.sch]
2025-08-26 Updating schematic to include all three CTs
    [doorbell.sch]
2025-08-28 Updating schematic to be multiple sheets, including gerber files for PCB, updating readme
    [current_sense_relay.kicad_sch, doorbell.kicad_pcb, doorbell.kicad_sch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]
2025-08-28 Adding image of PCB
